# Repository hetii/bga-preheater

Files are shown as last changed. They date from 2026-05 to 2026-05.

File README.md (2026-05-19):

# BGA REWORK STATION
Advanced Open-Source BGA Preheater Controller with Web Interface, Multi-Zone Heating, and Thermal Profile Management.
<p align="left">
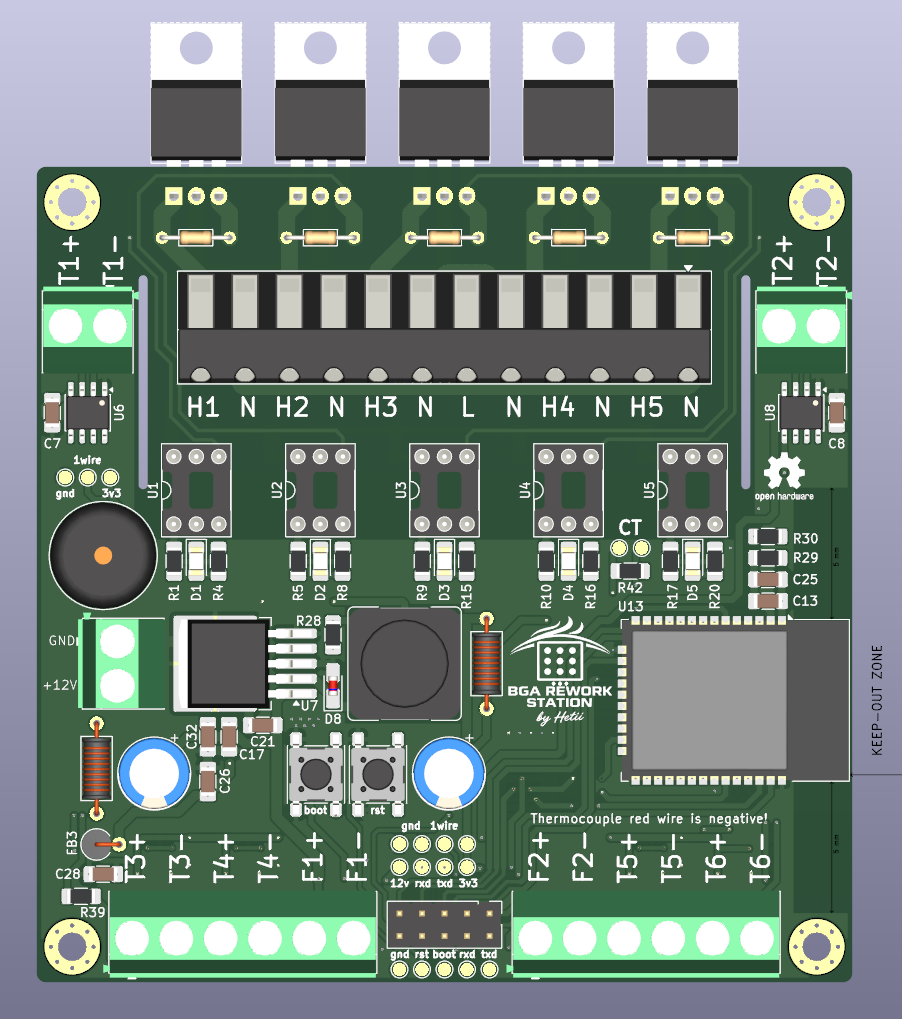
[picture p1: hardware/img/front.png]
  
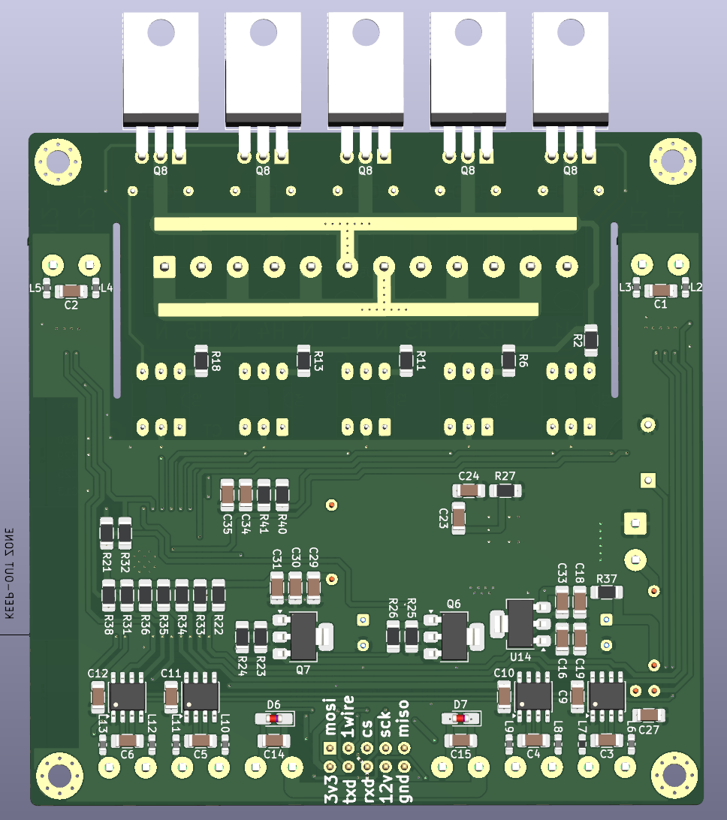
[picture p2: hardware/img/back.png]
  
</p>

---

## 📖 Overview

**BGA Rework Station** is a fully open-source project designed for controlling professional and DIY BGA/PCB preheating systems.

The controller supports multiple heating zones, thermocouple monitoring, fan control, and a modern web-based interface for managing the entire process directly from a browser.

The project is suitable for:
- BGA rework stations
- PCB preheaters
- SMT/reflow experiments
- Electronics repair workshops
- DIY thermal control systems

---

# ✨ Features

## 🔥 Multi-Zone Heater Control
- Control up to **5 independent heaters**
- Separate heating zones
- Real-time power management
- Suitable for IR heaters, ceramic heaters, hotplates, and custom heating systems

## 🌡️ Thermocouple Monitoring
- Support for **6 thermocouples** and ds18b20 sensors over 1 wire
- Real-time temperature acquisition
- Multi-point PCB temperature tracking
- Accurate thermal feedback for safe BGA processing

## 🌀 Fan Control
- PWM fan control support
- Automatic or manual cooling operation
- Active thermal stabilization

## 🌐 Web Interface
Built-in web application accessible from any browser.

Features include:
- Real-time temperature monitoring
- Heater control
- Fan management
- Profile editor
- System status monitoring
- Live thermal charts

## 💾 BGA Profile Management
- Save and load BGA heating profiles
- Custom temperature curves
- Repeatable rework processes
- Profile storage directly in the system

---

# 🛠️ Hardware Capabilities

| Feature | Specification |
|---|---|
| Heater Outputs | Up to 5 |
| Thermocouple Inputs | 6 |
| Fan Control | 2 x PWM Supported |
| Interface | Web Browser |
| Profile Storage | Supported |
| Open Source | Yes |

---

# 📂 Project Structure

```text
/
├── hardware
│   ├── grb
│   ├── img
│   ├── kicad
│   └── pdf
├── README.md
└── software
    ├── builder
    ├── builder.py
    ├── configs
    ├── html
    ├── include
    ├── requirements.txt
    └── src
```

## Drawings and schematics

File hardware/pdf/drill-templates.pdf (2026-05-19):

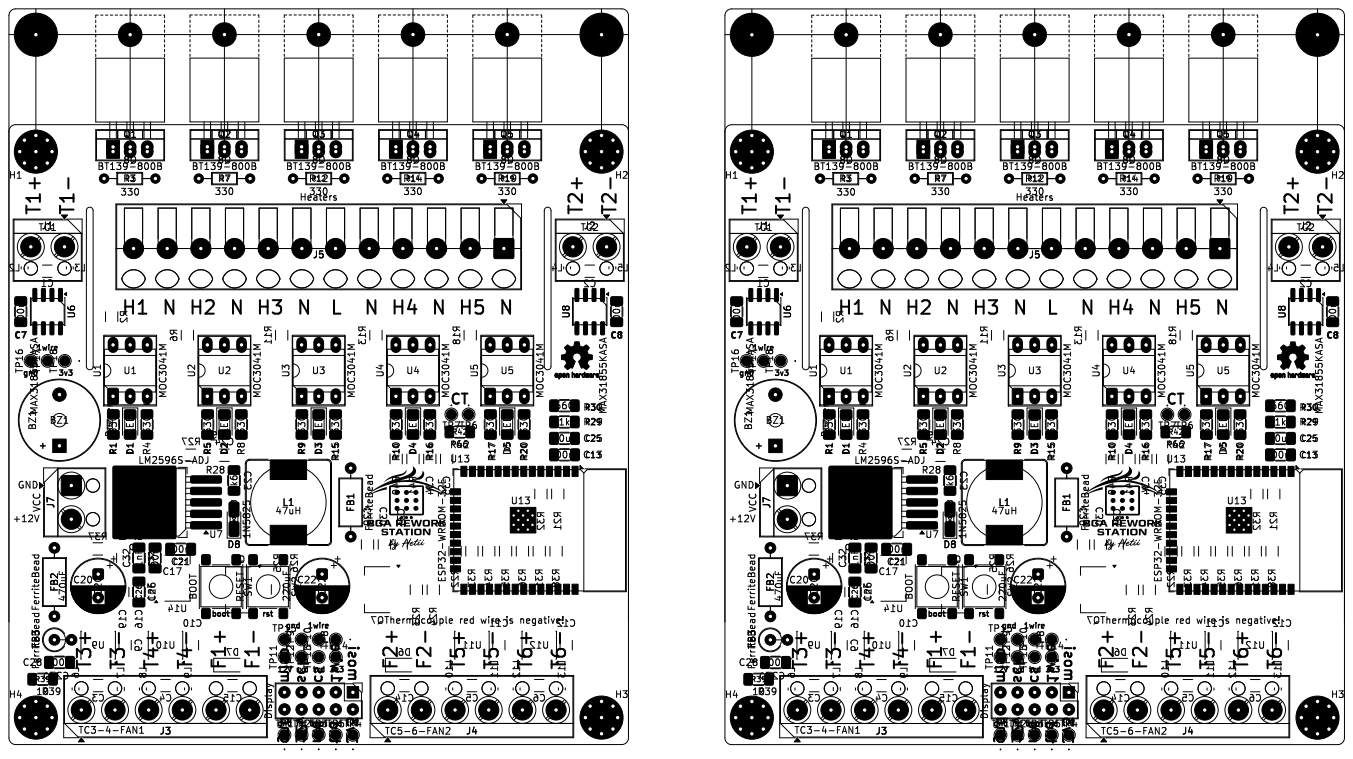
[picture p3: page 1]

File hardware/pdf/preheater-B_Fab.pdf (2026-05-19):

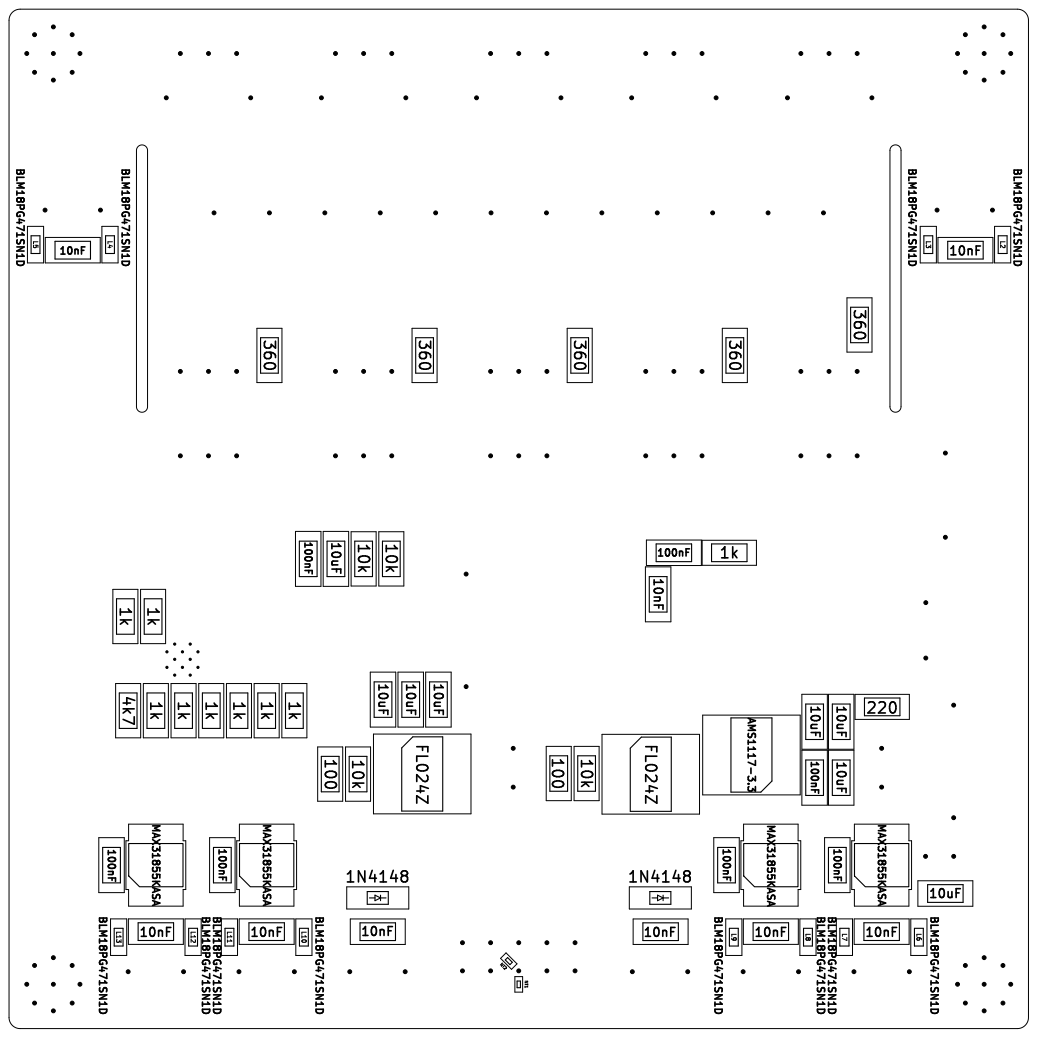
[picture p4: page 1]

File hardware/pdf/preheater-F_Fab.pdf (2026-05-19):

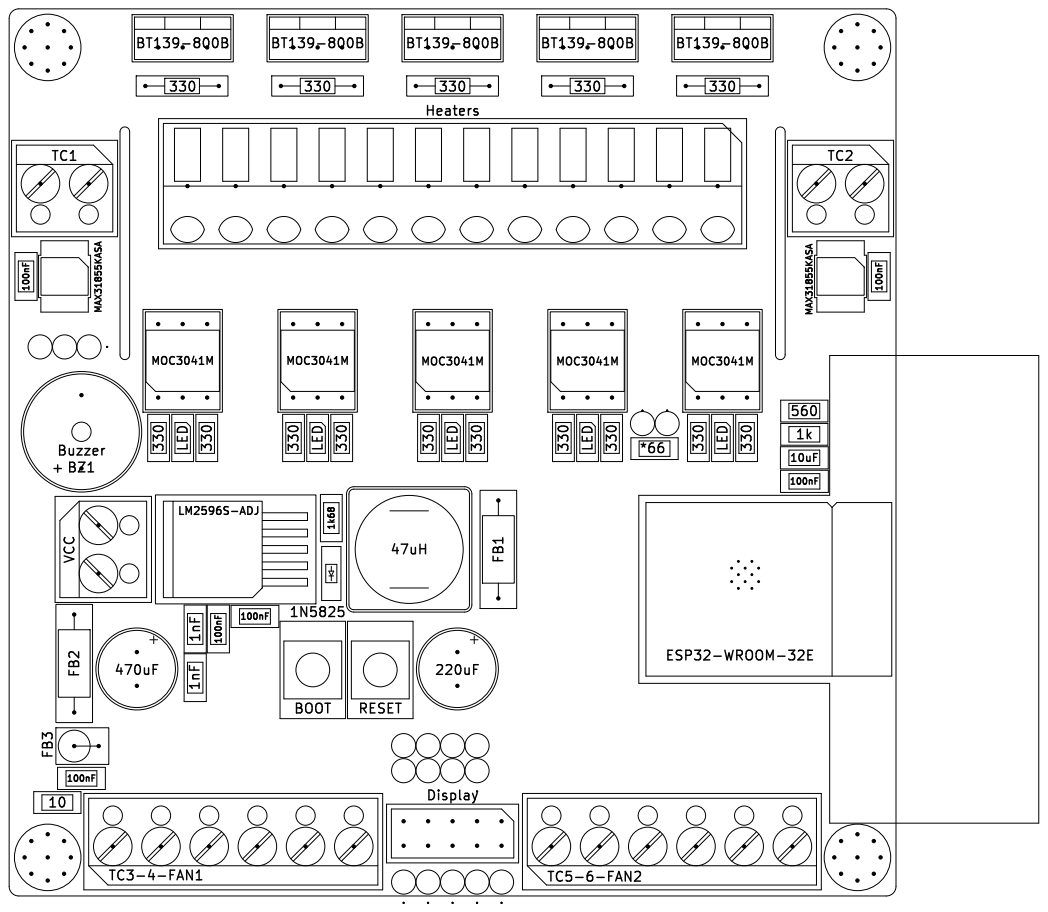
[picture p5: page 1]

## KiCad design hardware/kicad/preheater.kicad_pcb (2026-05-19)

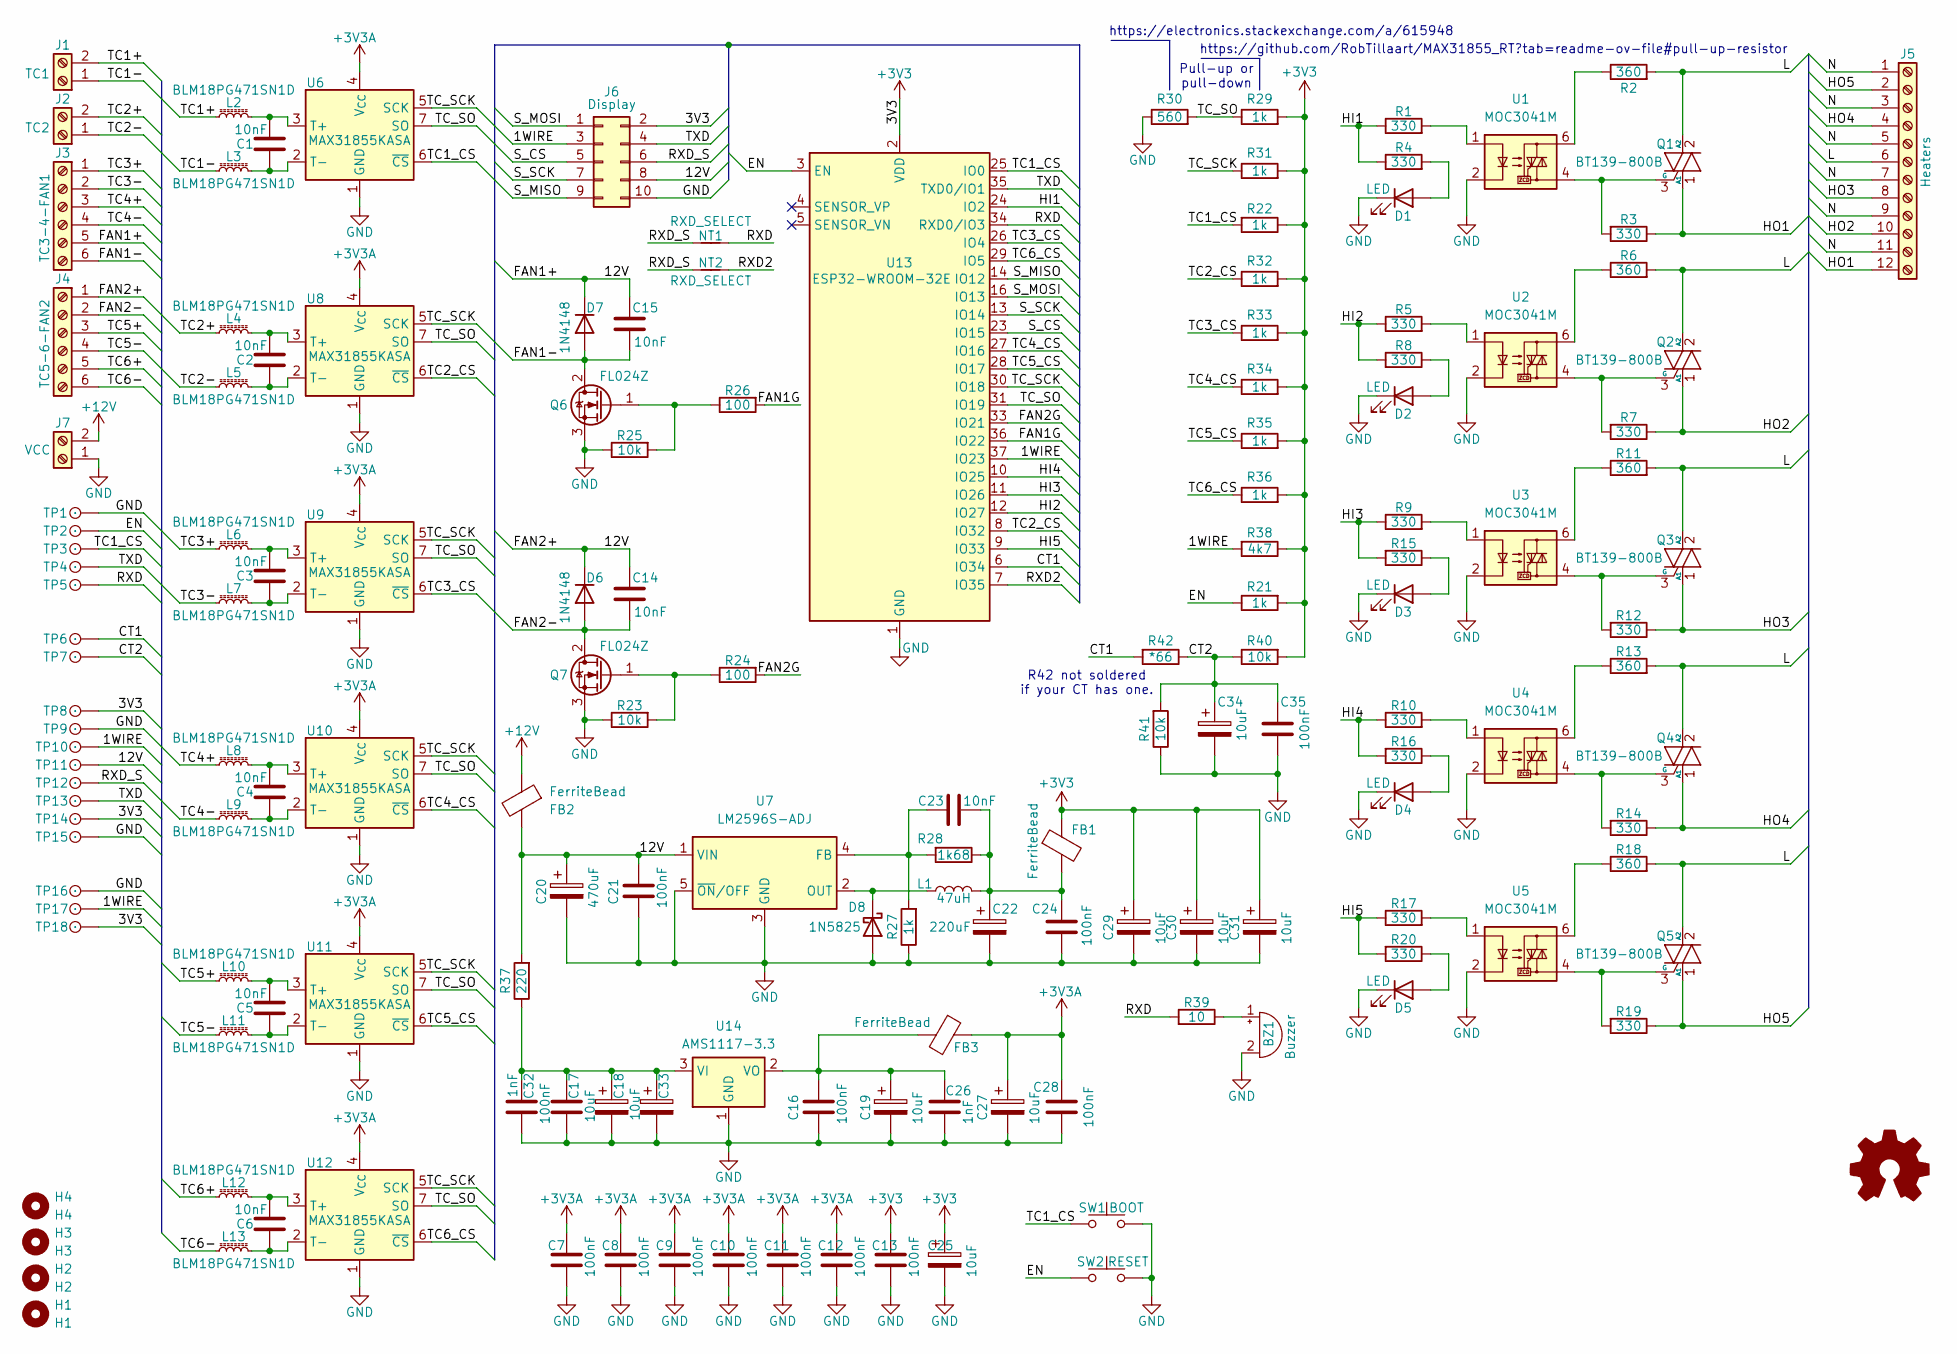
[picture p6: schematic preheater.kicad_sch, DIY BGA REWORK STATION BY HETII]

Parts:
BZ1: Buzzer; Buzzer_12x9.5RM7.6
C1, C2, C3, C4, C5, C6, C14, C15, C23: 10nF; C_1206_3216Metric_Pad1.33x1.80mm_HandSolder
C7, C8, C9, C10, C11, C12, C13, C16, C17, C21, C24, C28, C35: 100nF; C_1206_3216Metric_Pad1.33x1.80mm_HandSolder
C18, C19, C25, C27, C29, C30, C31, C33, C34: 10uF; C_1206_3216Metric_Pad1.33x1.80mm_HandSolder
C20: 470uF; CP_Radial_D8.0mm_P3.50mm
C22: 220uF; CP_Radial_D8.0mm_P3.50mm
C26, C32: 1nF; C_1206_3216Metric_Pad1.33x1.80mm_HandSolder
D1, D2, D3, D4, D5: LED; LED_1206_3216Metric_Pad1.42x1.75mm_HandSolder
D6, D7: 1N4148; D_MicroMELF_Handsoldering
D8: 1N5825; D_MicroMELF_Handsoldering
FB1, FB2: FerriteBead; L_Axial_L7.0mm_D3.3mm_P10.16mm_Horizontal_Fastron_MICC
FB3: FerriteBead; L_Axial_L7.0mm_D3.3mm_P2.54mm_Vertical_Fastron_MICC
H1: H1; MountingHole_3.2mm_M3_Pad_Via
H2: H2; MountingHole_3.2mm_M3_Pad_Via
H3: H3; MountingHole_3.2mm_M3_Pad_Via
H4: H4; MountingHole_3.2mm_M3_Pad_Via
J1: TC1; Altech_AK100_1x02_P5.00mm
J2: TC2; Altech_AK100_1x02_P5.00mm
J3: TC3-4-FAN1; Altech_AK100_1x06_P5.00mm
J4: TC5-6-FAN2; Altech_AK100_1x06_P5.00mm
J5: Heaters; Altech_AK300_1x12_P5.00mm_45-Degree
J6: Display; PinHeader_2x05_P2.54mm_Vertical
J7: VCC; Altech_AK100_1x02_P5.00mm
L1: 47uH; L_Bourns_SRR1260
L2, L3, L4, L5, L6, L8, L9, L10, L11, L12, L13: BLM18PG471SN1D; L_0603_1608Metric_Pad1.05x0.95mm_HandSolder
L7: BLM18PG471SN1D; R_0603_1608Metric_Pad0.98x0.95mm_HandSolder
NT1, NT2: RXD_SELECT; R_0201_0603Metric
Q1, Q2, Q3, Q4, Q5: BT139-800B; TO-220-3_Vertical
Q6, Q7: FL024Z; SOT-223-3_TabPin2
R1, R4, R5, R8, R9, R10, R15, R16, R17, R20: 330; R_1206_3216Metric_Pad1.30x1.75mm_HandSolder
R2, R6, R11, R13, R18: 360; R_1206_3216Metric_Pad1.30x1.75mm_HandSolder
R3, R7, R12, R14, R19: 330; R_Axial_DIN0204_L3.6mm_D1.6mm_P7.62mm_Horizontal
R21, R22, R27, R29, R31, R32, R33, R34, R35, R36: 1k; R_1206_3216Metric_Pad1.30x1.75mm_HandSolder
R23, R25, R40, R41: 10k; R_1206_3216Metric_Pad1.30x1.75mm_HandSolder
R24, R26: 100; R_1206_3216Metric_Pad1.30x1.75mm_HandSolder
R28: 1k68; R_1206_3216Metric_Pad1.30x1.75mm_HandSolder
R30: 560; R_1206_3216Metric_Pad1.30x1.75mm_HandSolder
R37: 220; R_1206_3216Metric_Pad1.30x1.75mm_HandSolder
R38: 4k7; R_1206_3216Metric_Pad1.30x1.75mm_HandSolder
R39: 10; R_1206_3216Metric_Pad1.30x1.75mm_HandSolder
R42: *66; R_1206_3216Metric_Pad1.30x1.75mm_HandSolder
SW1: BOOT; SW_SPST_PTS645Sx43SMTR92
SW2: RESET; SW_SPST_PTS645Sx43SMTR92
TP1, TP2, TP3, TP4, TP5, TP6, TP7, TP8, TP9, TP10, TP11, TP12, TP13, TP14, TP15, TP16, TP17, TP18: .; TestPoint_Pad_D1.5mm
U1, U2, U3, U4, U5: MOC3041M; DIP-6_W7.62mm_Socket_LongPads
U6, U8, U9, U10, U11, U12: MAX31855KASA; SOIC-8_3.9x4.9mm_P1.27mm
U7: LM2596S-ADJ; TO-263-5_TabPin3
U13: ESP32-WROOM-32E; ESP32-WROOM-32D
U14: AMS1117-3.3; SOT-223-3_TabPin2

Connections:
+3V3: C13.1, C25.1, C29.1, C30.1, C31.1, FB1.1, J6.2, R21.2, R22.1, R29.2, R31.2, R32.2, R33.2, R34.2, R35.2, R36.2, R38.1, R40.2, TP8.1, TP14.1, TP18.1, U13.2 (VDD)
+3V3A: C7.1, C8.1, C9.1, C10.1, C11.1, C12.1, C27.1, C28.2, FB3.1, U6.4 (V_{CC}), U8.4 (V_{CC}), U9.4 (V_{CC}), U10.4 (V_{CC}), U11.4 (V_{CC}), U12.4 (V_{CC})
+12V: FB2.1, J7.2
/1WIRE: J6.3, R38.2, TP10.1, TP17.1, U13.37 (IO23)
/12V: C14.1, C15.1, C20.1, C21.1, D6.1 (K), D7.1 (K), FB2.2, J3.5, J4.1, J6.8, R37.2, TP11.1, U7.1 (VIN)
/CT1: R42.2, TP6.1, U13.6 (IO34)
/CT2: C34.1, C35.1, R40.1, R41.2, R42.1, TP7.1
/EN: R21.1, SW2.1, TP2.1, U13.3 (EN)
/FAN1-: C15.2, D7.2 (A), J3.6, Q6.2 (D)
/FAN1G: R26.2, U13.36 (IO22)
/FAN2-: C14.2, D6.2 (A), J4.2, Q7.2 (D)
/FAN2G: R24.2, U13.33 (IO21)
/HI1: R1.1, R4.1, U13.24 (IO2)
/HI2: R5.1, R8.2, U13.12 (IO27)
/HI3: R9.1, R15.2, U13.11 (IO26)
/HI4: R10.1, R16.2, U13.10 (IO25)
/HI5: R17.1, R20.2, U13.9 (IO33)
/HO1: J5.12, Q1.1 (A1), R3.1
/HO2: J5.10, Q2.1 (A1), R7.1
/HO3: J5.8, Q3.1 (A1), R12.1
/HO4: J5.4, Q4.1 (A1), R14.1
/HO5: J5.2, Q5.1 (A1), R19.1
/L: J5.6, Q1.2 (A2), Q2.2 (A2), Q3.2 (A2), Q4.2 (A2), Q5.2 (A2), R2.2, R6.2, R11.2, R13.2, R18.2
/N: J5.1, J5.3, J5.5, J5.7, J5.9, J5.11
/RXD: NT1.2, R39.2, TP5.1, U13.34 (RXD0/IO3)
/RXD2: NT2.2, U13.7 (IO35)
/RXD_S: J6.6, NT1.1, NT2.1, TP12.1
/S_CS: J6.5, U13.23 (IO15)
/S_MISO: J6.9, U13.14 (IO12)
/S_MOSI: J6.1, U13.16 (IO13)
/S_SCK: J6.7, U13.13 (IO14)
/TC1+: J1.2, L2.2
/TC1-: J1.1, L3.2
/TC1_CS: R22.2, SW1.1, TP3.1, U6.6 (~CS), U13.25 (IO0)
/TC2+: J2.2, L4.2
/TC2-: J2.1, L5.2
/TC2_CS: R32.1, U8.6 (~CS), U13.8 (IO32)
/TC3+: J3.1, L6.2
/TC3-: J3.2, L7.2
/TC3_CS: R33.1, U9.6 (~CS), U13.26 (IO4)
/TC4+: J3.3, L8.2
/TC4-: J3.4, L9.2
/TC4_CS: R34.1, U10.6 (~CS), U13.27 (IO16)
/TC5+: J4.3, L10.2
/TC5-: J4.4, L11.2
/TC5_CS: R35.1, U11.6 (~CS), U13.28 (IO17)
/TC6+: J4.5, L12.2
/TC6-: J4.6, L13.2
/TC6_CS: R36.1, U12.6 (~CS), U13.29 (IO5)
/TC_SCK: R31.1, U6.5 (SCK), U8.5 (SCK), U9.5 (SCK), U10.5 (SCK), U11.5 (SCK), U12.5 (SCK), U13.30 (IO18)
/TC_SO: R29.1, R30.2, U6.7 (SO), U8.7 (SO), U9.7 (SO), U10.7 (SO), U11.7 (SO), U12.7 (SO), U13.31 (IO19)
/TXD: J6.4, TP4.1, TP13.1, U13.35 (TXD0/IO1)
GND: BZ1.2 (-), C7.2, C8.2, C9.2, C10.2, C11.2, C12.2, C13.2, C16.2, C17.2, C18.2, C19.2, C20.2, C21.2, C22.2, C24.2, C25.2, C26.2, C27.2, C28.1, C29.2, C30.2, C31.2, C32.2, C33.2, C34.2, C35.2, D1.1 (K), D2.1 (K), D3.1 (K), D4.1 (K), D5.1 (K), D8.2 (A), J6.10, J7.1, Q6.3 (S), Q7.3 (S), R23.1, R25.1, R27.1, R30.1, R41.1, SW1.2, SW2.2, TP1.1, TP9.1, TP15.1, TP16.1, U1.2, U2.2, U3.2, U4.2, U5.2, U6.1 (GND), U7.3 (GND), U7.5 (~ON/OFF), U8.1 (GND), U9.1 (GND), U10.1 (GND), U11.1 (GND), U12.1 (GND), U13.1 (GND), U13.15 (GND), U13.38 (GND), U13.39 (GND), U14.1 (GND)
unnamed: BZ1.1 (+), R39.1
unnamed: C22.1, C23.2, C24.1, FB1.2, L1.2, R28.1
unnamed: D1.2 (A), R4.2
unnamed: D2.2 (A), R8.1
unnamed: D3.2 (A), R15.1
unnamed: D4.2 (A), R16.1
unnamed: D5.2 (A), R20.1
unnamed: D8.1 (K), L1.1, U7.2 (OUT)
unnamed: Q1.3 (G), R3.2, U1.4
unnamed: Q2.3 (G), R7.2, U2.4
unnamed: Q3.3 (G), R12.2, U3.4
unnamed: Q4.3 (G), R14.2, U4.4
unnamed: Q5.3 (G), R19.2, U5.4
unnamed: Q6.1 (G), R25.2, R26.1
unnamed: Q7.1 (G), R23.2, R24.1
unnamed: R1.2, U1.1
unnamed: R2.1, U1.6
unnamed: R5.2, U2.1
unnamed: R6.1, U2.6
unnamed: R9.2, U3.1
unnamed: R10.2, U4.1
unnamed: R11.1, U3.6
unnamed: R13.1, U4.6
unnamed: R17.2, U5.1
unnamed: R18.1, U5.6
unnamed: C1.1, L2.1, U6.3 (T+)
unnamed: C1.2, L3.1, U6.2 (T-)
unnamed: C23.1, R27.2, R28.2, U7.4 (FB)
unnamed: C2.1, L4.1, U8.3 (T+)
unnamed: C2.2, L5.1, U8.2 (T-)
unnamed: C3.1, L6.1, U9.3 (T+)
unnamed: C3.2, L7.1, U9.2 (T-)
unnamed: C4.1, L8.1, U10.3 (T+)
unnamed: C4.2, L9.1, U10.2 (T-)
unnamed: C5.1, L10.1, U11.3 (T+)
unnamed: C5.2, L11.1, U11.2 (T-)
unnamed: C6.1, L12.1, U12.3 (T+)
unnamed: C6.2, L13.1, U12.2 (T-)
unnamed: C17.1, C18.1, C32.1, C33.1, R37.1, U14.3 (VI)
unnamed: C16.1, C19.1, C26.1, FB3.2, U14.2 (VO)

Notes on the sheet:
R42 not soldered if your CT has one.
Pull-up or pull-down
https://electronics.stackexchange.com/a/615948
https://github.com/RobTillaart/MAX31855_RT?tab=readme-ov-file#pull-up-resistor

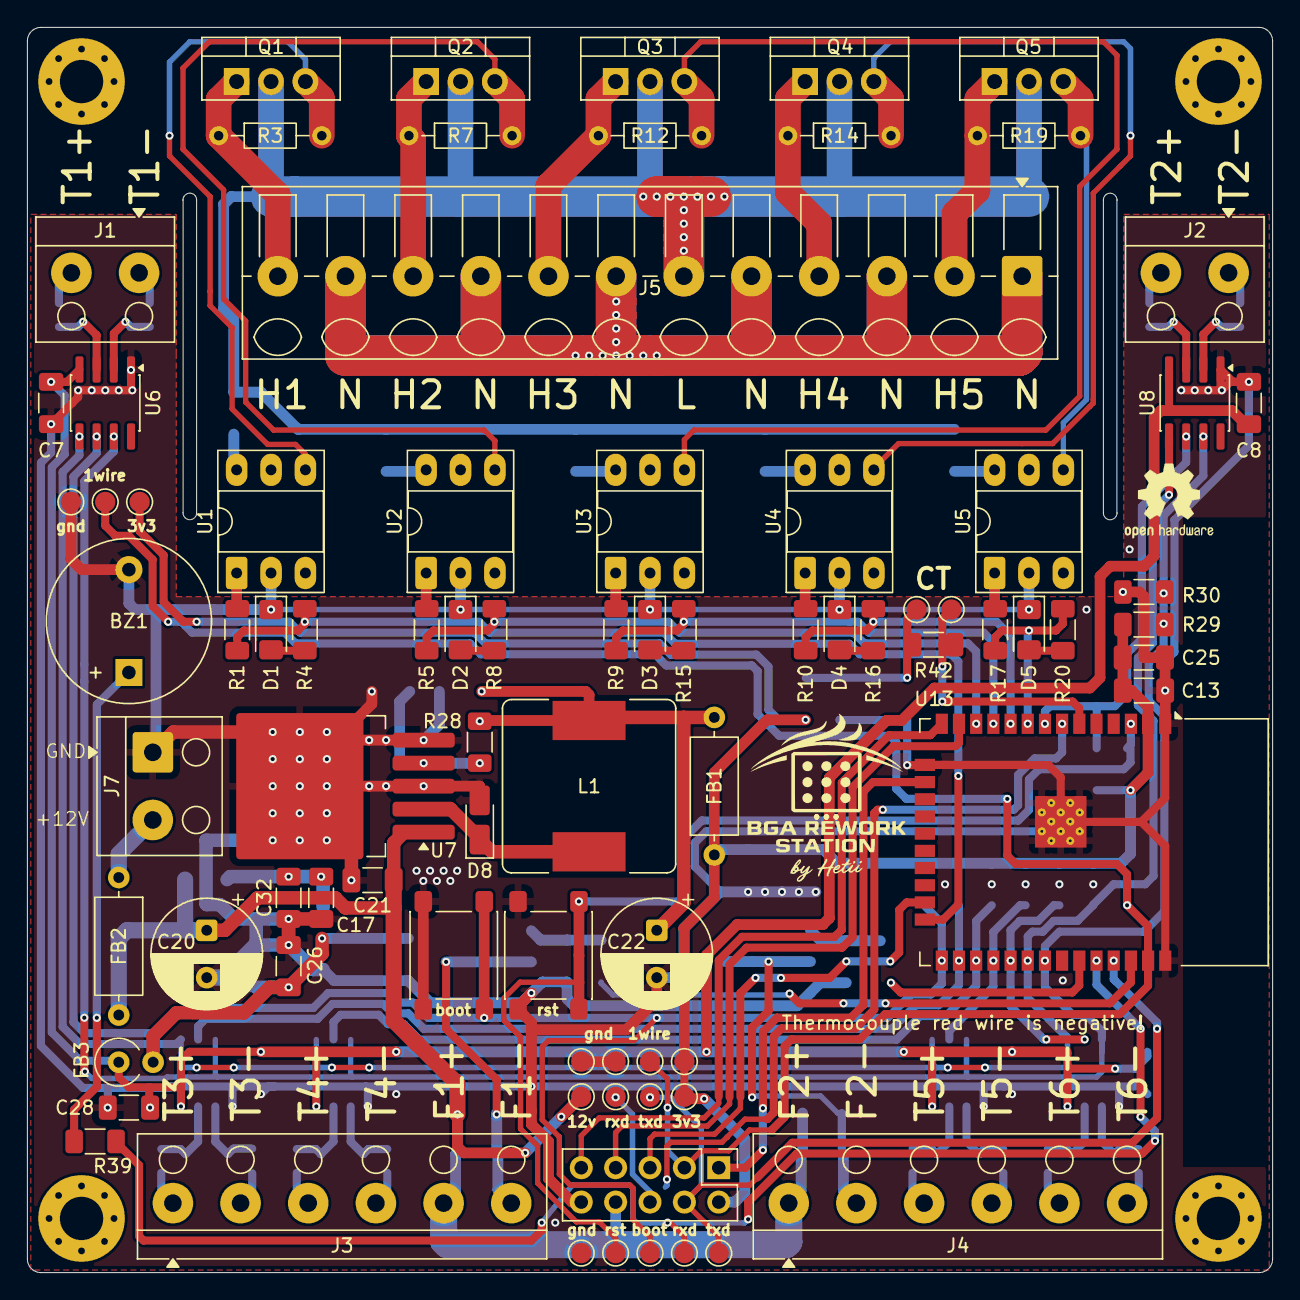
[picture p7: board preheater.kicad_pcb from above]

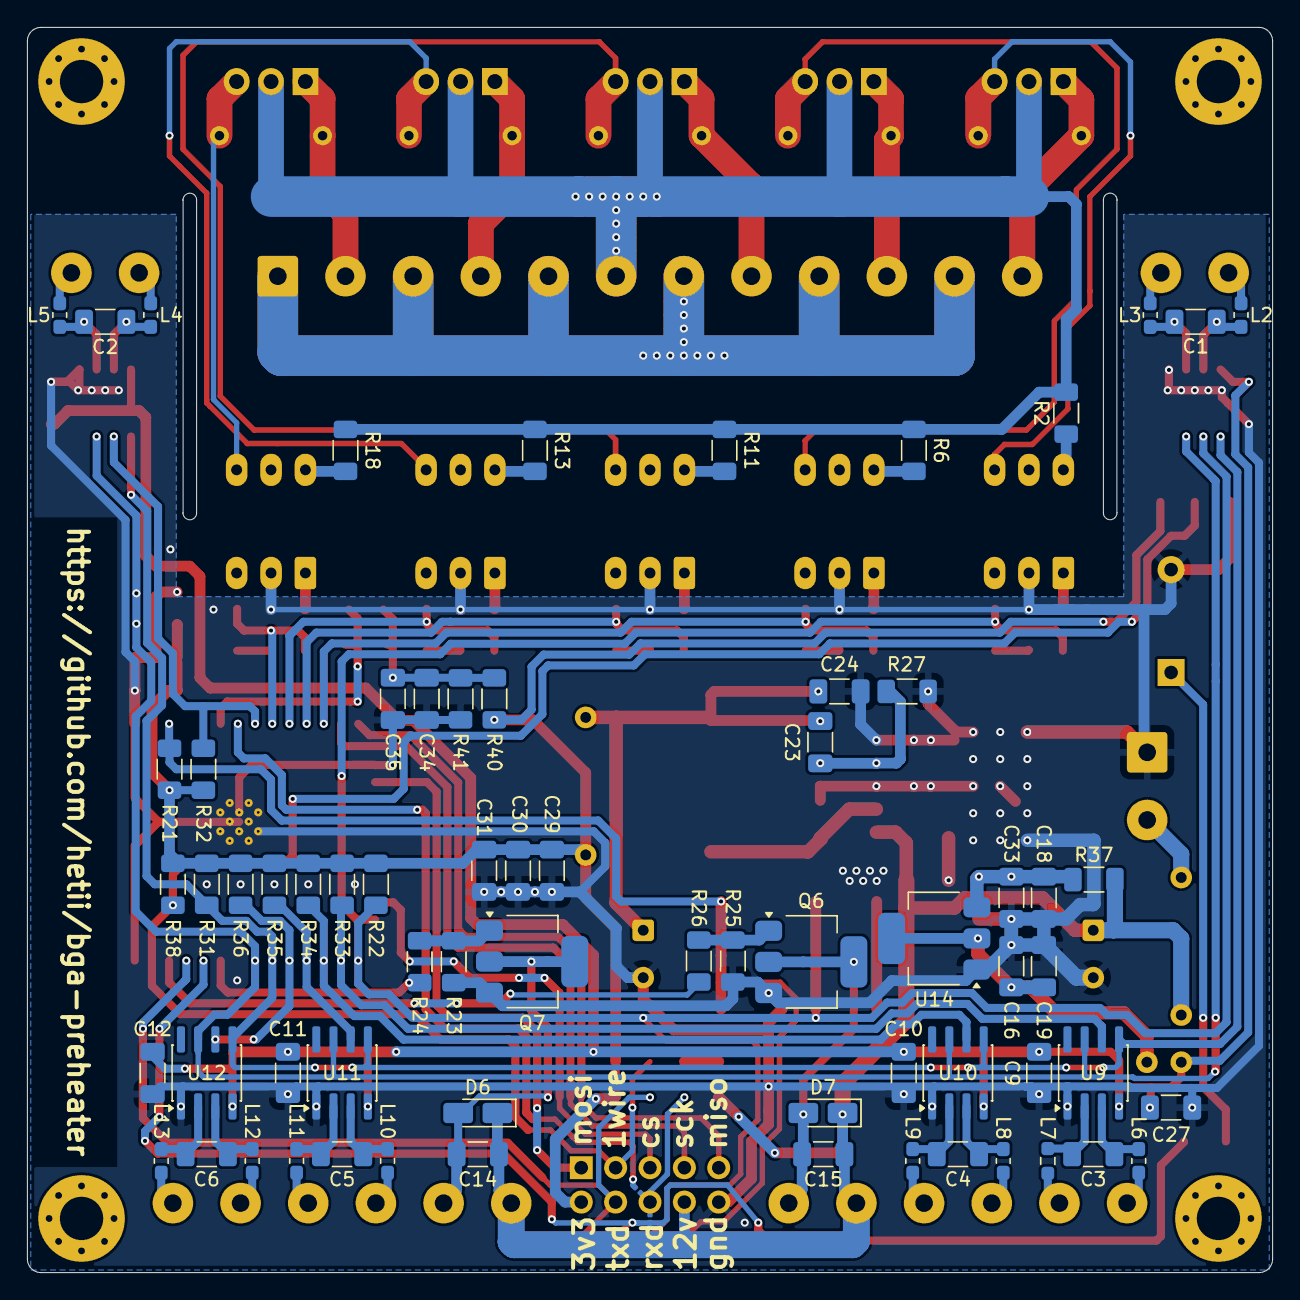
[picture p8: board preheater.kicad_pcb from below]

Board: 2 copper layers, 92.0 x 92.0 mm, 157 parts (69 on the bottom side), 93 nets.

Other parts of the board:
...: LOGO
